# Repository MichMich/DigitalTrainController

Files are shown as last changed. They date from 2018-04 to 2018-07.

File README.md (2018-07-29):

# DigitalTrainController

This repository contains all the sourcecode as well as the KiCad project for the [Digital Train Controller](http://michaelteeuw.nl/tagged/trainautomator) i built for my dad's model train. 

For more info about this project, check out my blog: http://michaelteeuw.nl/tagged/trainautomator

Feel free to use this code and PCB project, but keep in mind that it comes without ANY form of support. :)



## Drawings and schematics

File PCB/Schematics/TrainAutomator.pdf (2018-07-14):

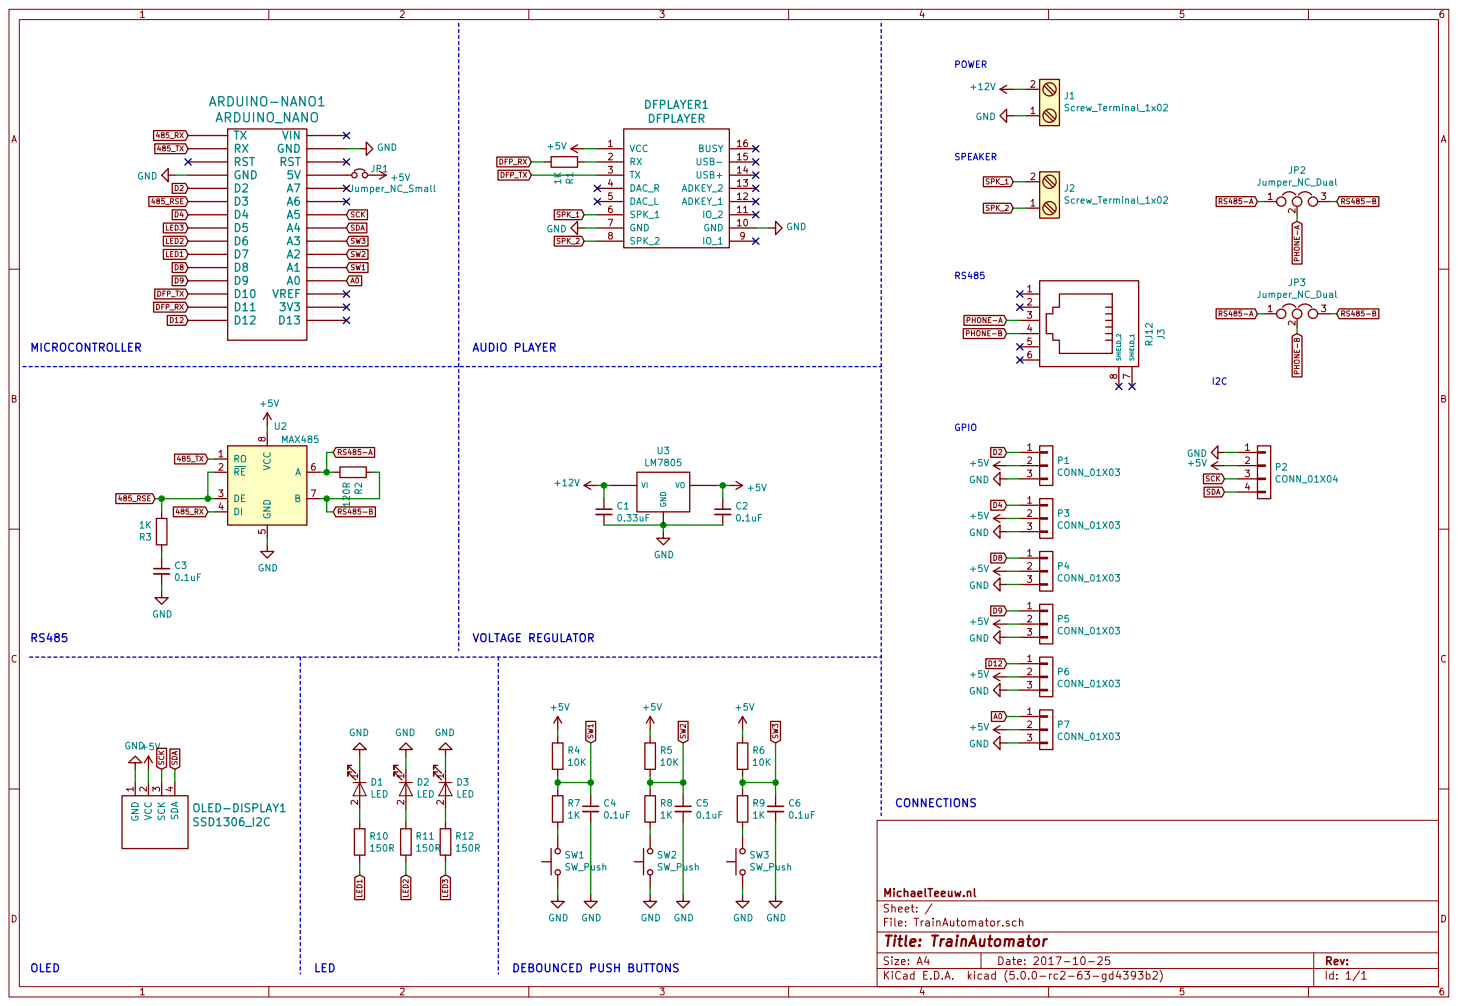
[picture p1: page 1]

Id: 1/1 Title: TrainAutomator File: TrainAutomator.sch Sheet: / MichaelTeeuw.nl

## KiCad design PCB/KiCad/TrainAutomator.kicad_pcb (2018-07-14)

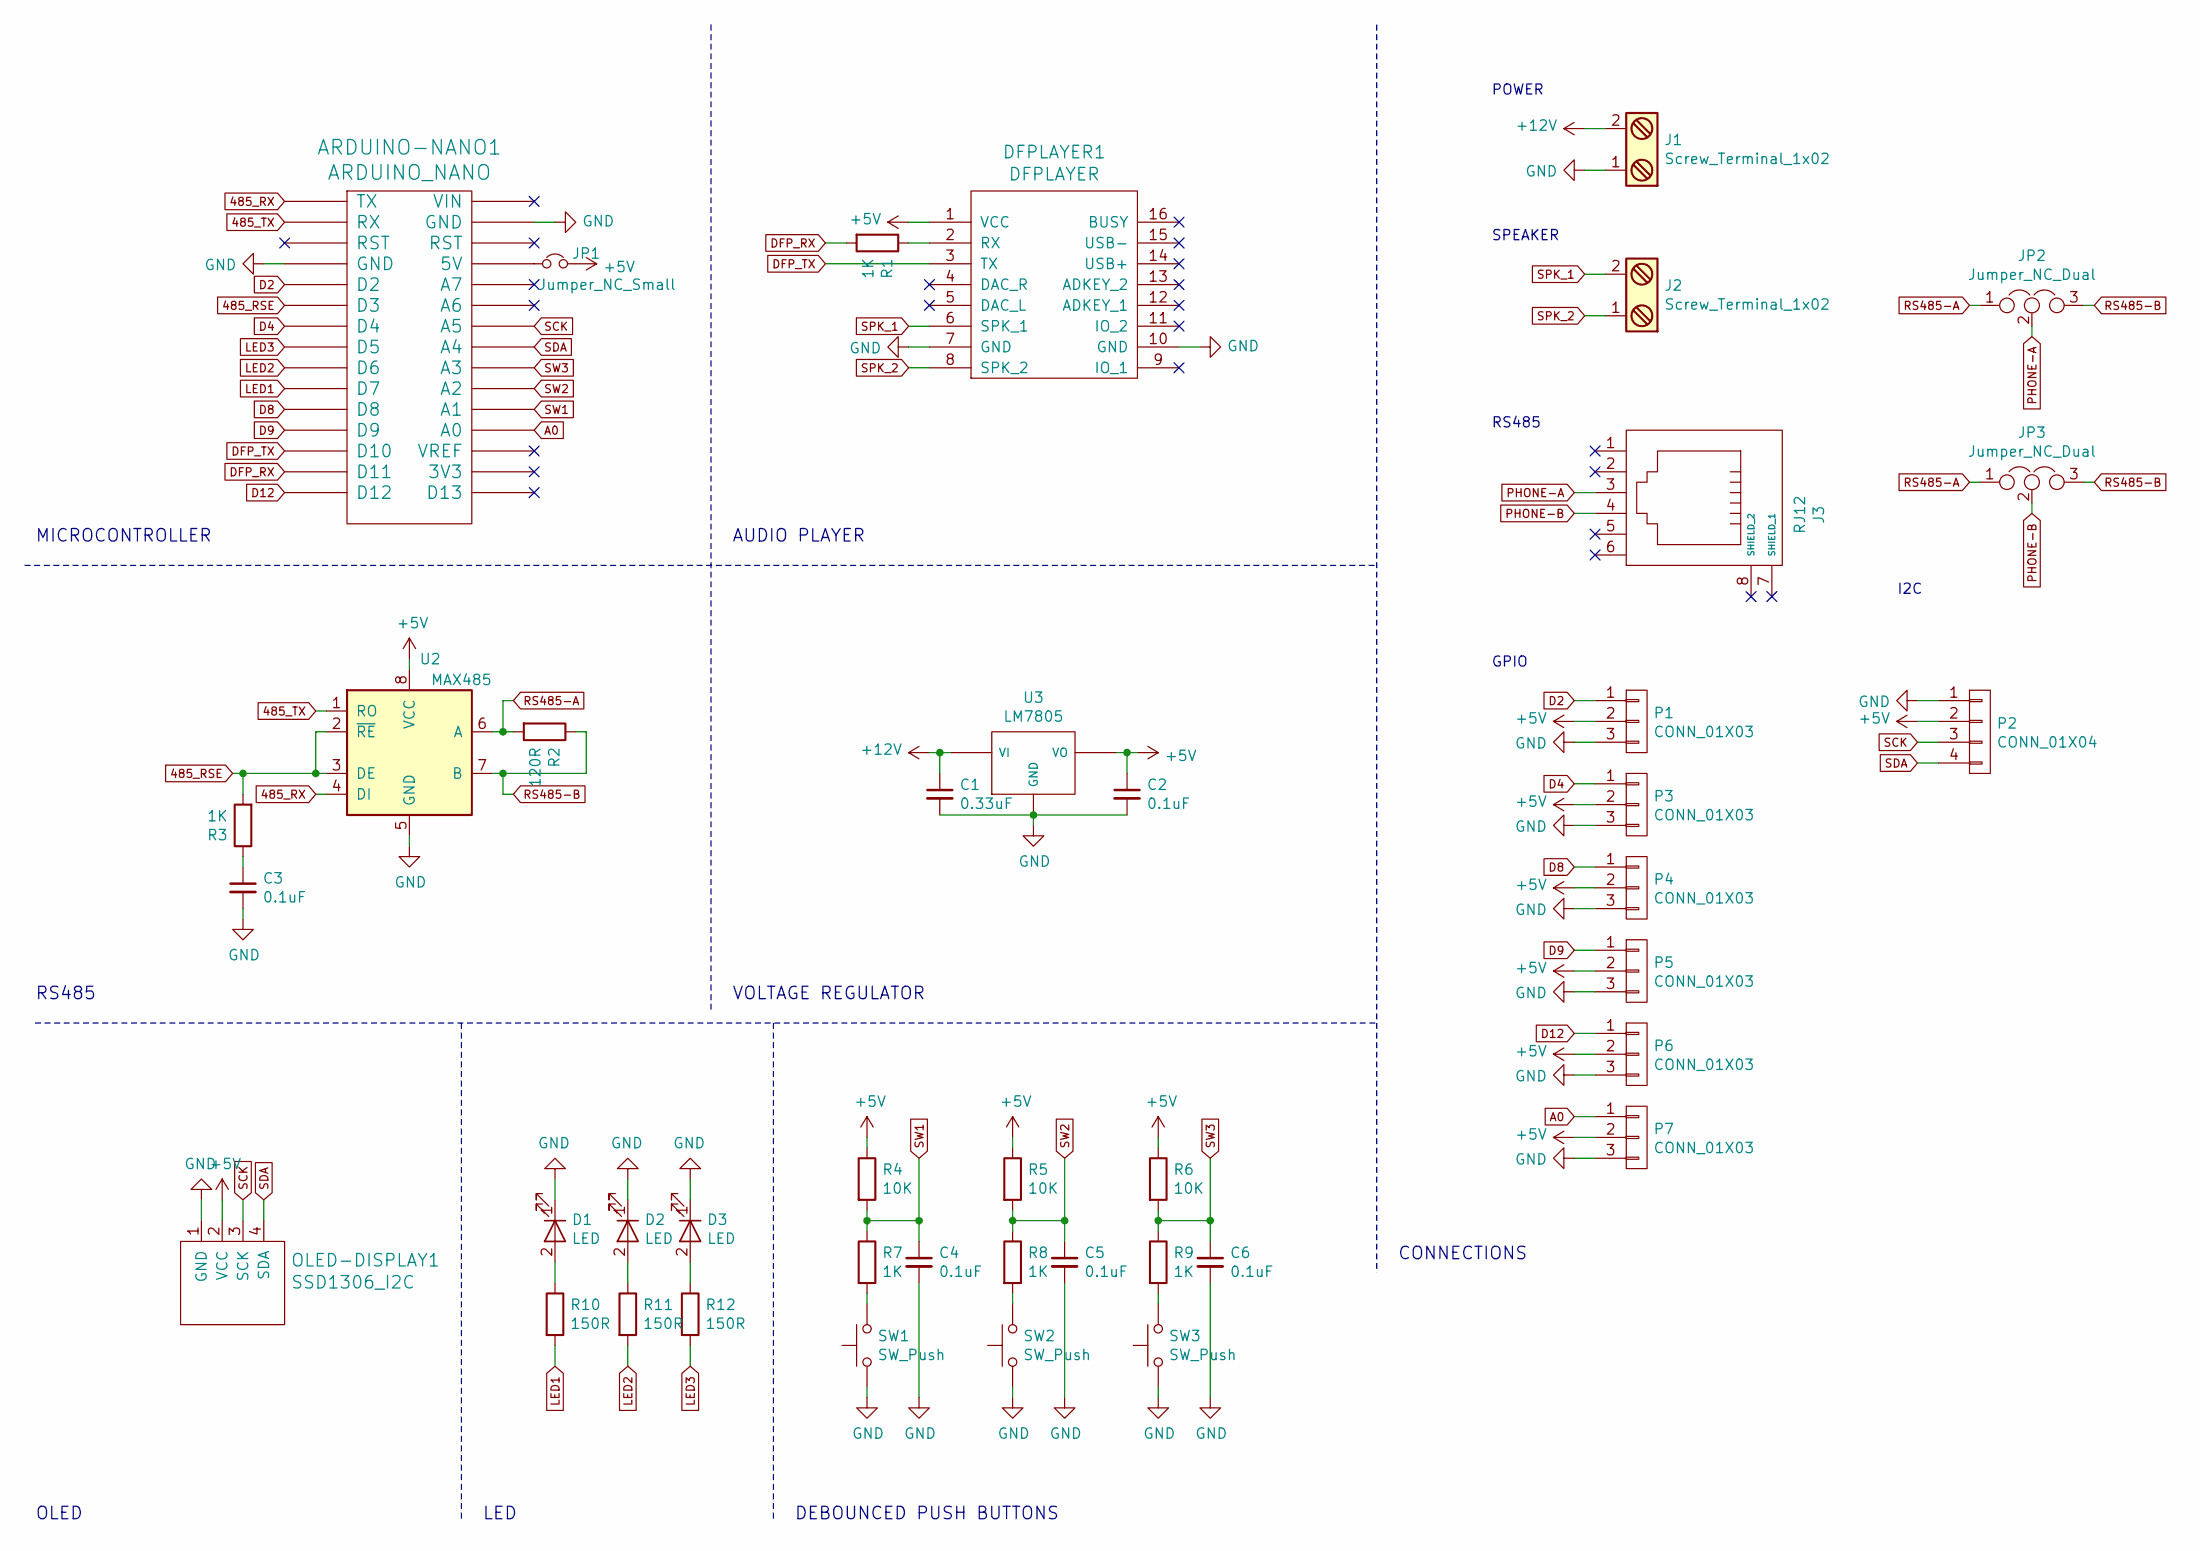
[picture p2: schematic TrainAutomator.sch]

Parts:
ARDUINO-NANO1: ARDUINO_NANO; ArduinoNano
C1: 0.33uF; C_0805_HandSoldering
C2, C3, C4, C5, C6: 0.1uF; C_0805_HandSoldering
D1, D2, D3: LED; LED_1206_HandSoldering
DFPLAYER1: DFPLAYER; DFPlayerMini
J1, J2: Screw_Terminal_1x02; TerminalBlock_4UCON_19963_02x3.5mm_Straight
J3: RJ12
JP1: Jumper_NC_Small; Pin_Header_Straight_1x02_Pitch2.00mm
JP2, JP3: Jumper_NC_Dual; DualJumper-NC
OLED-DISPLAY1: SSD1306_I2C; SSD1306-096-OLED-I2C
P1, P3, P4, P5, P6, P7: CONN_01X03; JST_PH_S3B-PH-K_03x2.00mm_Angled
P2: CONN_01X04; JST_PH_S4B-PH-K_04x2.00mm_Angled
R1, R3, R7, R8, R9: 1K; R_0805_HandSoldering
R2: 120R; R_0805_HandSoldering
R4, R5, R6: 10K; R_0805_HandSoldering
R10, R11, R12: 150R; R_0805_HandSoldering
SW1, SW2, SW3: SW_Push; SW_SPST_EVQPE1
U2: MAX485; SOIC-8_3.9x4.9mm_Pitch1.27mm
U3: LM7805; TO-263-2

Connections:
485_RSE: ARDUINO-NANO1.6 (D3), R3.2, U2.2 (~RE~), U2.3 (DE)
485_RX: ARDUINO-NANO1.1 (TX), U2.4 (DI)
485_TX: ARDUINO-NANO1.2 (RX), U2.1 (RO)
+5V: C2.1, DFPLAYER1.1 (VCC), JP1.2, OLED-DISPLAY1.2 (VCC), P1.2, P2.2, P3.2, P4.2, P5.2, P6.2, P7.2, R4.1, R5.1, R6.1, U2.8 (VCC), U3.3 (VO)
+12V: C1.1, J1.2, U3.1 (VI)
A0: ARDUINO-NANO1.19 (A0), P7.1
D2: ARDUINO-NANO1.5 (D2), P1.1
D4: ARDUINO-NANO1.7 (D4), P3.1
D8: ARDUINO-NANO1.11 (D8), P4.1
D9: ARDUINO-NANO1.12 (D9), P5.1
D12: ARDUINO-NANO1.15 (D12), P6.1
DFP_RX: ARDUINO-NANO1.14 (D11), R1.2
DFP_TX: ARDUINO-NANO1.13 (D10), DFPLAYER1.3 (TX)
GND: ARDUINO-NANO1.4 (GND), ARDUINO-NANO1.29 (GND), C1.2, C2.2, C3.2, C4.2, C5.2, C6.2, D1.1 (K), D2.1 (K), D3.1 (K), DFPLAYER1.7 (GND), DFPLAYER1.10 (GND), J1.1, OLED-DISPLAY1.1 (GND), P1.3, P2.1, P3.3, P4.3, P5.3, P6.3, P7.3, SW1.1, SW2.1, SW3.1, U2.5 (GND), U3.2 (GND)
LED1: ARDUINO-NANO1.10 (D7), R10.2
LED2: ARDUINO-NANO1.9 (D6), R11.2
LED3: ARDUINO-NANO1.8 (D5), R12.2
unnamed: ARDUINO-NANO1.27 (5V), JP1.1
unnamed: C3.1, R3.1
unnamed: D1.2 (A), R10.1
unnamed: D2.2 (A), R11.1
unnamed: D3.2 (A), R12.1
unnamed: DFPLAYER1.2 (RX), R1.1
unnamed: R7.2, SW1.2
unnamed: R8.2, SW2.2
unnamed: R9.2, SW3.2
PHONE-A: J3.3, JP2.2
PHONE-B: J3.4, JP3.2
RS485-A: JP2.1, JP3.1, R2.2, U2.6 (A)
RS485-B: JP2.3, JP3.3, R2.1, U2.7 (B)
SCK: ARDUINO-NANO1.24 (A5), OLED-DISPLAY1.3 (SCK), P2.3
SDA: ARDUINO-NANO1.23 (A4), OLED-DISPLAY1.4 (SDA), P2.4
SPK_1: DFPLAYER1.6 (SPK_1), J2.2
SPK_2: DFPLAYER1.8 (SPK_2), J2.1
SW1: ARDUINO-NANO1.20 (A1), C4.1, R4.2, R7.1
SW2: ARDUINO-NANO1.21 (A2), C5.1, R5.2, R8.1
SW3: ARDUINO-NANO1.22 (A3), C6.1, R6.2, R9.1

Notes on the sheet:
MICROCONTROLLER
RS485
OLED
LED
DEBOUNCED PUSH BUTTONS
VOLTAGE REGULATOR
AUDIO PLAYER
CONNECTIONS
GPIO
RS485
SPEAKER
POWER
I2C

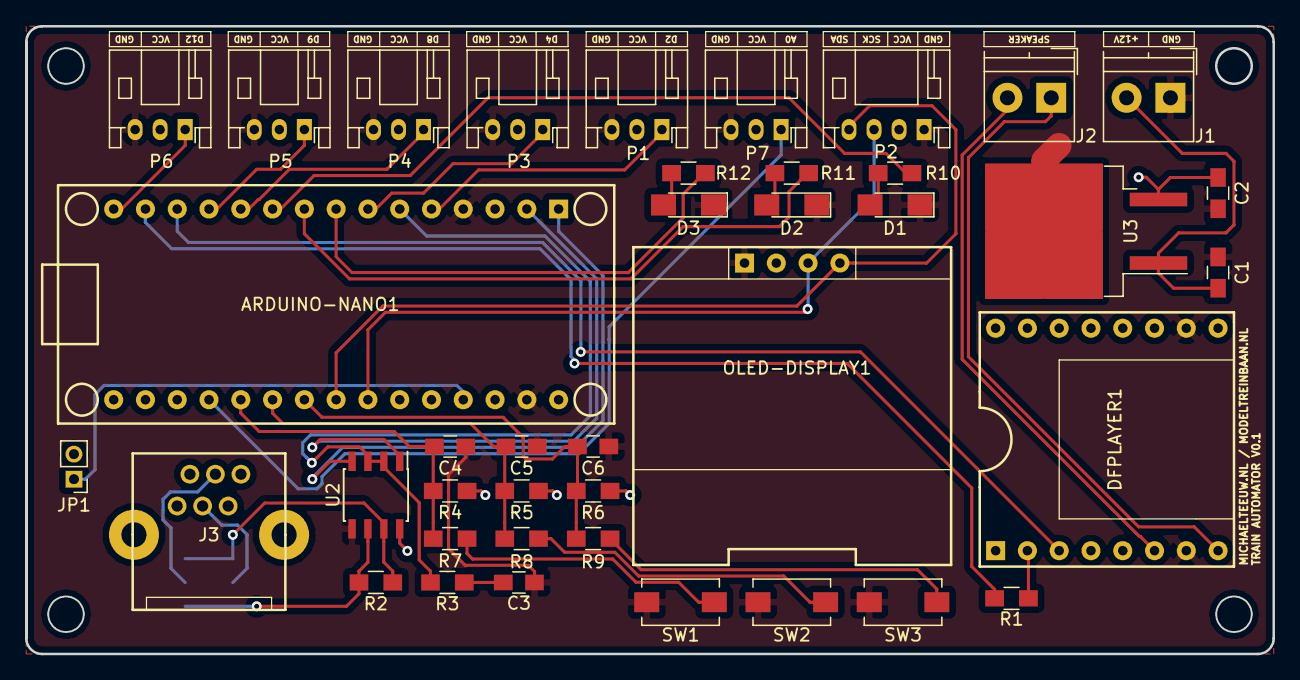
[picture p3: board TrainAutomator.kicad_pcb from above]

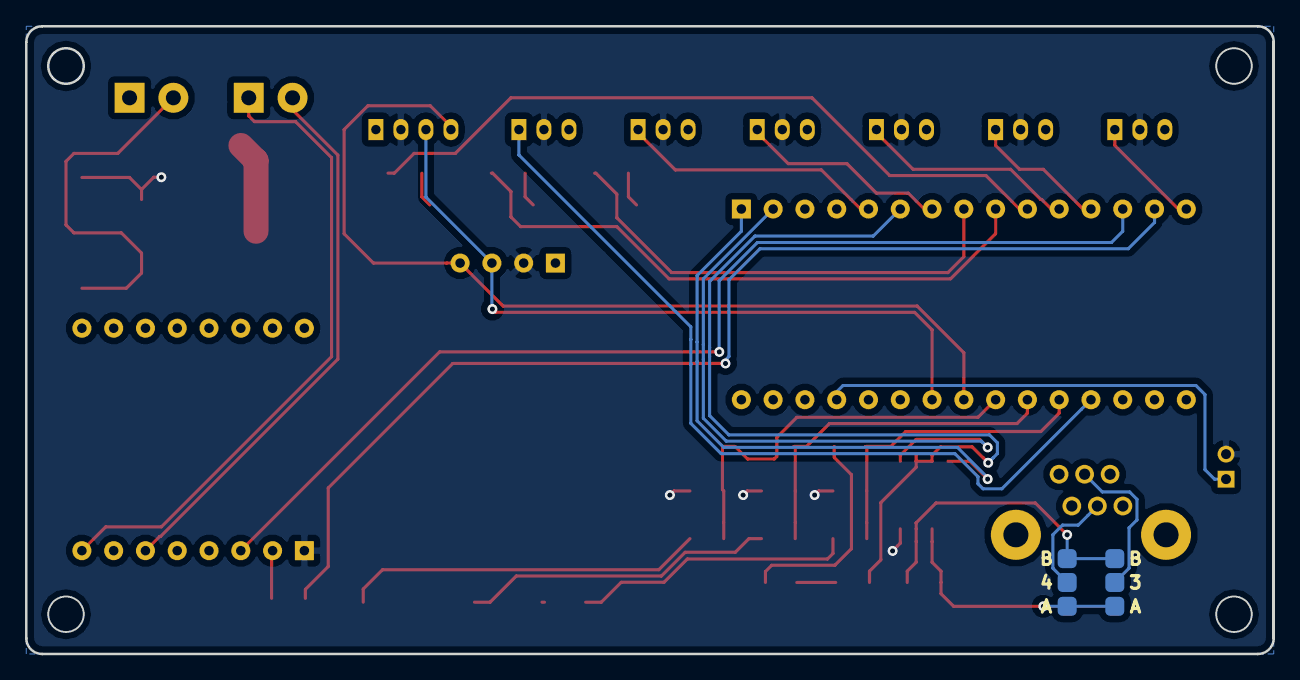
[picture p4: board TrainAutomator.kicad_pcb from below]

Board: 2 copper layers, 99.7 x 50.2 mm, 42 parts (2 on the bottom side), 37 nets.

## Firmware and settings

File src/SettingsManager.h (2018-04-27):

#include <Arduino.h>
#include <U8g2lib.h>

#define SETTINGS_VERSION 1 // Changing this value will cause the Arduino to reset the EEPROM values.

#define DEFAULT_TRAIN_ID 89
#define DEFAULT_TRAIN_SPEED 32
#define DEFAULT_VOLUME 15
#define DEFAULT_AUTODRIVE_MINTIME 30
#define DEFAULT_AUTODRIVE_MAXTIME 90
#define DEFAULT_TRAINSOUND_MINTIME 10
#define DEFAULT_TRAINSOUND_MAXTIME 60
#define DEFAULT_STATIONSOUND_MINTIME 10
#define DEFAULT_STATIONSOUND_MAXTIME 60

enum SettingIdentifier : int {
    SettingTrainID = 1,
    SettingTrainSpeed = 2,
    SettingVolume = 3,
    SettingAutoDriveMinTime = 4,
    SettingAutoDriveMaxTime = 5,
    SettingTrainSoundMinTime = 6,
    SettingTrainSoundMaxTime = 7,
    SettingStationSoundMinTime = 8,
    SettingStationSoundMaxTime = 9
};

class SettingsManager {
    public:
        SettingsManager();
        int8_t getSettingFor(SettingIdentifier identifier);
        bool setSettingFor(SettingIdentifier identifier, int8_t value);
        void writeDefaults();
        void editAutoDriveSettings();
        void editTrainSoundSettings();
        void editStationSoundSettings();
        void setDisplayController(U8G2 &displayController);

    private:
        void userInputForSetting(SettingIdentifier setting, const char *title, const char *pre, uint8_t lo, uint8_t hi, uint8_t digits, const char *post);
        U8G2 u8g2;
};

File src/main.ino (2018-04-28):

#include "DisplayController.h"
#include <Button.h>
#include <Task.h>
#include "RandomTimeTask.h"
#include "SoundPlayer.h"
#include "TrainController.h"
#include "SettingsManager.h"

#define BUTTON_1 A1
#define BUTTON_2 A2
#define BUTTON_3 A3

#define LED_1 5
#define LED_2 6
#define LED_3 7

SettingsManager settingsManager;
TaskManager taskManager;
SoundPlayer soundPlayer;
TrainController trainController;
RandomTimeTask autoDriveTask(1000);
RandomTimeTask trainSoundTask(1000);
RandomTimeTask stationSoundTask(1000);

Button button1 = Button(A1, false, true, 25);
Button button2 = Button(A2, false, true, 25);
Button button3 = Button(A3, false, true, 25);

DisplayController displayController;

bool autoDrive = false;
bool trainSound = false;
bool stationSound = false;

void setup() {
  pinMode(LED_1, OUTPUT);
  pinMode(LED_2, OUTPUT);
  pinMode(LED_3, OUTPUT);

  displayController.init();
  displayController.setStatusMessage(F("BOOTING"), true);

  settingsManager.setDisplayController(displayController.u8g2);

  soundPlayer.init();
  trainController.init();

  setCallbacks();  
  loadSettings();

  displayController.setStatusMessage(String("FOUND SOUND FILES: " + String(soundPlayer.getSongCount())), true);
}

void loop() {
  checkButtons();
  taskManager.Loop();
  
  trainController.handle();

  displayController.setAutoDriveTime(autoDriveTask.remainingTimeInSeconds());
  displayController.setTrainSoundTime(trainSoundTask.remainingTimeInSeconds());
  displayController.setStationSoundTime(stationSoundTask.remainingTimeInSeconds());
  displayController.setTrainStateAndLocation(trainController.getTrainState(), trainController.getTrainLocation());

  displayController.update();  
}

void autoDriveDepart()
{
  trainController.startTrain();
  if (trainController.getTrainLocation() == TrainLocationEast) {
    displayController.setStatusMessage(F("DEPART FROM STATION EAST"));
  } else {
    displayController.setStatusMessage(F("DEPART FROM STATION WEST"));
  }
  digitalWrite(LED_1, HIGH);
  delay(10);
  digitalWrite(LED_1, LOW);
}

void trainSoundPlay()
{
  int8_t num = trainController.playRandomSound();
  displayController.setStatusMessage(String("PLAYING TRAIN SOUND: " + String(num)));
  digitalWrite(LED_2, HIGH);
  delay(10);
  digitalWrite(LED_2, LOW);
}

void stationSoundPlay()
{
  int num = soundPlayer.playRandomSound();
  displayController.setStatusMessage(String("PLAYING STATION SOUND: " + String(num)));
  digitalWrite(LED_3, HIGH);
  delay(10);
  digitalWrite(LED_3, LOW);
}

void setCallbacks() {
  trainController.setArrivalCallback([](TrainLocation location) {
    if (location == TrainLocationEast) {
      displayController.setStatusMessage(F("ARRIVED AT STATION EAST"));
    } else {
      displayController.setStatusMessage(F("ARRIVED AT STATION WEST"));
    }
    if (autoDrive) taskManager.StartTask(&autoDriveTask);
  });


  autoDriveTask.setCallback(autoDriveDepart);
  trainSoundTask.setCallback(trainSoundPlay);
  stationSoundTask.setCallback(stationSoundPlay);
}

void loadSettings() {
  trainController.setTrainID(settingsManager.getSettingFor(SettingTrainID));
  trainController.setSpeed(settingsManager.getSettingFor(SettingTrainSpeed));
  
  soundPlayer.setVolume(settingsManager.getSettingFor(SettingVolume));
  
  autoDriveTask.setMinMaxTime((uint32_t) settingsManager.getSettingFor(SettingAutoDriveMinTime) * (uint32_t) 1000, (uint32_t) settingsManager.getSettingFor(SettingAutoDriveMaxTime) * (uint32_t) 1000);
  trainSoundTask.setMinMaxTime((uint32_t) settingsManager.getSettingFor(SettingTrainSoundMinTime) * (uint32_t) 1000, (uint32_t) settingsManager.getSettingFor(SettingTrainSoundMaxTime) * (uint32_t) 1000);
  stationSoundTask.setMinMaxTime((uint32_t) settingsManager.getSettingFor(SettingStationSoundMinTime) * (uint32_t) 1000, (uint32_t) settingsManager.getSettingFor(SettingStationSoundMaxTime) * (uint32_t) 1000);
}

void checkButtons() 
{
  button1.read();
  button2.read();
  button3.read();

  if (button1.pressedFor(3000) && trainController.getTrainState() == TrainStateStopped) {
    showSettingsLoadScreen();
    settingsManager.editAutoDriveSettings();
    loadSettings();
    return;
  }

  if (button2.pressedFor(3000) && trainController.getTrainState() == TrainStateStopped) {
    showSettingsLoadScreen();
    settingsManager.editTrainSoundSettings();
    loadSettings();
    return;
  }

  if (button3.pressedFor(3000) && trainController.getTrainState() == TrainStateStopped) {
    showSettingsLoadScreen();
    settingsManager.editStationSoundSettings();
    loadSettings();
    return;
  }

  if(button1.wasReleased()) {
    autoDrive = !autoDrive;
    displayController.setSchedulerState(AutomaticDriveScheduler, autoDrive);
    if (autoDrive) {
      autoDriveDepart();
      displayController.setStatusMessage(F("AUTO DRIVE ENABLED"));
    } else {
      taskManager.StopTask(&autoDriveTask);
      displayController.setStatusMessage(F("AUTO DRIVE DISABLED"));
    }
  }

  if(button2.wasReleased()) {
    trainSound = !trainSound;
    trainController.setSoundEnabled(trainSound);
    displayController.setSchedulerState(TrainSoundScheduler, trainSound);
    if (trainSound) {
      trainSoundPlay();
      taskManager.StartTask(&trainSoundTask);
      displayController.setStatusMessage(F("TRAIN SOUND ENABLED"));
    } else {
      taskManager.StopTask(&trainSoundTask);
      displayController.setStatusMessage(F("TRAIN SOUND DISABLED"));
    }
  }

  if(button3.wasReleased()) {
    stationSound = !stationSound;
    displayController.setSchedulerState(StationSoundScheduler, stationSound);
    if (stationSound) {
      stationSoundPlay();
      taskManager.StartTask(&stationSoundTask);
      displayController.setStatusMessage(F("STATION SOUND ENABLED"));
    } else {
      taskManager.StopTask(&stationSoundTask);
      displayController.setStatusMessage(F("STATION SOUND DISABLED"));
    }
  }
}

void showSettingsLoadScreen()
{
  wdt_reset();
  wdt_disable();

  autoDrive = false;
  displayController.setSchedulerState(AutomaticDriveScheduler, autoDrive);
  taskManager.StopTask(&autoDriveTask);

  trainSound = false;
  trainController.setSoundEnabled(trainSound);
  displayController.setSchedulerState(TrainSoundScheduler, trainSound);
  taskManager.StopTask(&trainSoundTask);

  stationSound = false;
  displayController.setSchedulerState(StationSoundScheduler, stationSound);
  taskManager.StopTask(&stationSoundTask);

  displayController.u8g2.clear();
  while(!digitalRead(BUTTON_1) || !digitalRead(BUTTON_2) || !digitalRead(BUTTON_3));
}

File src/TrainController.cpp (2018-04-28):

#include "TrainController.h"

TrainController::TrainController()
{

}

void TrainController::init()
{
    pinMode(BUTTON_EAST, INPUT_PULLUP);
    pinMode(BUTTON_WEST, INPUT_PULLUP);
    pinMode(LED_BUILTIN, OUTPUT);

    XpressNet.start(XNetAddress, XNetSRPin);    //Initialisierung XNet-Bus

    _trainState = TrainStateStopped;
}

void TrainController::handle()
{
    XpressNet.receive();
    checkButtons();
}

void TrainController::setTrainID(int8_t id)
{   
    _trainID = id;
}

void TrainController::setSpeed(int8_t speed)
{
    _speed = speed;
}


void TrainController::startTrain()
{
    startTrain((_trainLocation != TrainLocationEast) ? TrainLocationEast : TrainLocationWest);
}

void TrainController::startTrain(TrainLocation destination)
{
    if (_trainState == TrainStateDriving) return;

    playSound(TrainSoundWistle);
    
    byte speed = (destination == TrainLocationEast) ? _speed  : _speed + 128;
    XpressNet.setLocoDrive(0x00, _trainID, 0x13, speed);

    _trainState = TrainStateDriving;
}

void TrainController::stopTrain()
{
    TrainController::XpressNet.setLocoDrive(0x00, _trainID, 0x13, 0);

    _trainState = TrainStateStopped;
}

void TrainController::setArrivalCallback(TrainArrivedCallbackFunction callback)
{
    _arrivalCallback = callback;
}

TrainState TrainController::getTrainState()
{
    return _trainState;
}

TrainLocation TrainController::getTrainLocation()
{
    return _trainLocation;
}

void TrainController::setSoundEnabled(bool enabled)
{
    _soundEnabled = enabled;
    if (enabled) startSound(TrainSoundSteamEngine);
    if (!enabled) stopAllSounds();
}

void TrainController::startSound(TrainSound sound)
{
    if(_soundEnabled) XpressNet.setLocoFunc(0x00, _trainID, 1, sound);
}

void TrainController::stopSound(TrainSound sound)
{
    XpressNet.setLocoFunc(0x00, _trainID, 0, sound);
}

void TrainController::playSound(TrainSound sound)
{
    startSound(sound);
    stopSound(sound);
}

void TrainController::stopAllSounds()
{
    for( int8_t soundIndex = 0; soundIndex < sizeof(_allSounds); soundIndex++ ){
        TrainSound sound = _allSounds[soundIndex];
        stopSound(sound);
    }
}

int8_t TrainController::playRandomSound()
{
    TrainSound sound = getRandomSound();
    playSound(sound);
    return sound;
}

// PRIVATE

void TrainController::checkButtons()
{
  if (!digitalRead(BUTTON_EAST) && _trainLocation != TrainLocationEast) {
    _trainLocation = TrainLocationEast;
    stopTrain();
    _arrivalCallback(_trainLocation);
  }

  if (!digitalRead(BUTTON_WEST) && _trainLocation != TrainLocationWest) {
    _trainLocation = TrainLocationWest;
    stopTrain();
    _arrivalCallback(_trainLocation);
  }

}

TrainSound TrainController::getRandomSound()
{
    TrainSound newTrainSound;
    do {
        newTrainSound = _randomSounds[random(sizeof(_randomSounds))];
    } while(newTrainSound == _lastRandomSound);
    _lastRandomSound = newTrainSound;

    return newTrainSound;
}

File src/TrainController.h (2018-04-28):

#include <Arduino.h>
#include <XpressNet.h>

#ifndef TrainController_h
#define TrainController_h

#define XNetAddress 31    //Adresse im XpressNet
#define XNetSRPin 3       //Max485 Busdriver Send/Receive-PIN

#define TRAIN_ID 89
#define SPEED 32

#define BUTTON_EAST 12
#define BUTTON_WEST 9

enum TrainLocation {
    TrainLocationEast,
    TrainLocationWest
};

enum TrainState  : int8_t {
    TrainStateDriving = 1,
    TrainStateStopped = 2
};

enum TrainSound : int8_t {
    TrainSoundSteamEngine = 1,
    TrainSoundWistle = 2,
    TrainSoundBell = 3,
    TrainSoundShortWistle = 4,
    TrainSoundShovel = 5,
    TrainSoundWistleEngineDriver = 7,
};

class TrainController {
    public: 
        typedef void (*TrainArrivedCallbackFunction)(TrainLocation location);

        TrainController();
        void init();
        void handle();

        void setTrainID(int8_t id);
        void setSpeed(int8_t speed);

        void startTrain();
        void startTrain(TrainLocation destination);
        void stopTrain();

        void setArrivalCallback(TrainArrivedCallbackFunction callback);

        TrainState getTrainState();
        TrainLocation getTrainLocation();

        void setSoundEnabled(bool enabled);
        void startSound(TrainSound sound);
        void stopSound(TrainSound sound);
        void playSound(TrainSound sound);
        void stopAllSounds();
        int8_t playRandomSound();


    private:
        TrainSound _allSounds[6] = {
            TrainSoundSteamEngine,
            TrainSoundWistle,
            TrainSoundBell,
            TrainSoundShortWistle,
            TrainSoundShovel,
            TrainSoundWistleEngineDriver
        };

        TrainSound _randomSounds[4] = {
            TrainSoundBell,
            TrainSoundShortWistle,
            TrainSoundShovel,
            TrainSoundWistleEngineDriver
        };

        XpressNetClass XpressNet;
        TrainArrivedCallbackFunction _arrivalCallback;

        int8_t _trainID = TRAIN_ID;
        int8_t _speed = SPEED;
        TrainLocation _trainLocation;
        TrainState _trainState;
        TrainSound _lastRandomSound;
        bool _soundEnabled;

        void checkButtons();
        TrainSound getRandomSound();
};

#endif

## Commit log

2018-04-25 Seperate sound timers.
2018-04-28 Indicator and fixes minor issues.
    [main.ino]
2018-07-14 Add PCB files.
    [TrainAutomator-2018-06-23-20-17-59.sch, TrainAutomator-2018-07-14-12-39-07.sch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]
